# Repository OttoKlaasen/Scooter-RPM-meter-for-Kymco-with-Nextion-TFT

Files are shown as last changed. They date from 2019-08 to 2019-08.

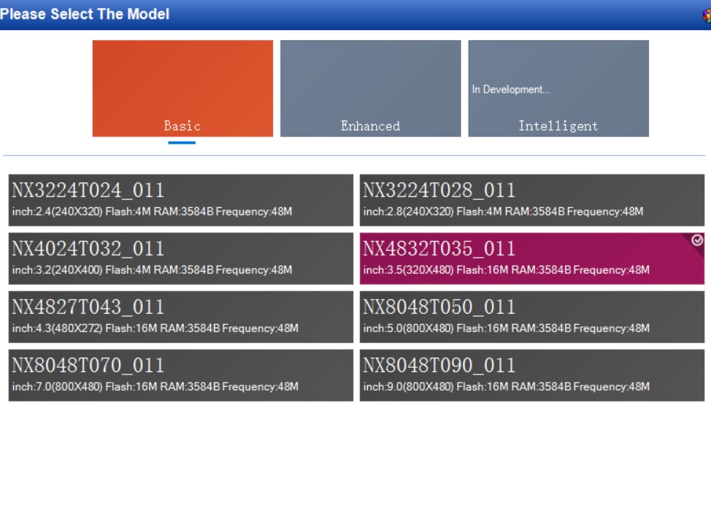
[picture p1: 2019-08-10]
Nextion Display used.jpg

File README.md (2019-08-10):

# Scooter-RPM-meter-for-Kymco-with-Nextion-TFT
Scooter-RPM-meter-for-Kymco-with-Nextion-TFT, display has yellow Ferrari RPM display, RTC on board, Temp and humid meter and oil meter.
Of course this can be used for any brand of scooter, i have a kymco agility 50cc.
This RPM meter goes to 8000 RPM and has been tested for many months and works great.

This project contains the Arduino code, all STL files for printing, the images file for your Nextion Display and a circuit for the pickup detector.
For the pickup detector i have PCB's available which you have to built yourself, you can have one PCB (without components for 2 euro excluding shipping.
The schematic file is on this page.

The Arduino i used is an Arduina Nano, further I used a temp.hum sensor and a rtc clock and of course a Nextion Display.

You also need a buck convertor to convert the 12V bat supply to 5V for the Arduina, the sensor runs on 12V and is interface with an opto-coupler on the main board. Schematic for the main board i dont have, should be easy to figure out from the code.
If you get stuck while building this you can contact me for help.

The TFT file need to be loaded into the Nextion display with an SD card, place the file in the root of the SD card and power the dispay, the file should be loaded automatically.

Temp/Hum meter:  https://nl.aliexpress.com/item/32759158558.html?spm=a2g0s.9042311.0.0.27424c4dwhILO9

RTC: https://nl.aliexpress.com/item/2037934408.html?spm=a2g0s.9042311.0.0.27424c4dwhILO9

Oil Temp meter: https://nl.aliexpress.com/item/1297739612.html?spm=a2g0s.9042311.0.0.27424c4d40bAqC

Nextion Display:  https://nl.aliexpress.com/item/32810467897.html?spm=a2g0s.9042311.0.0.27424c4dopPIMa

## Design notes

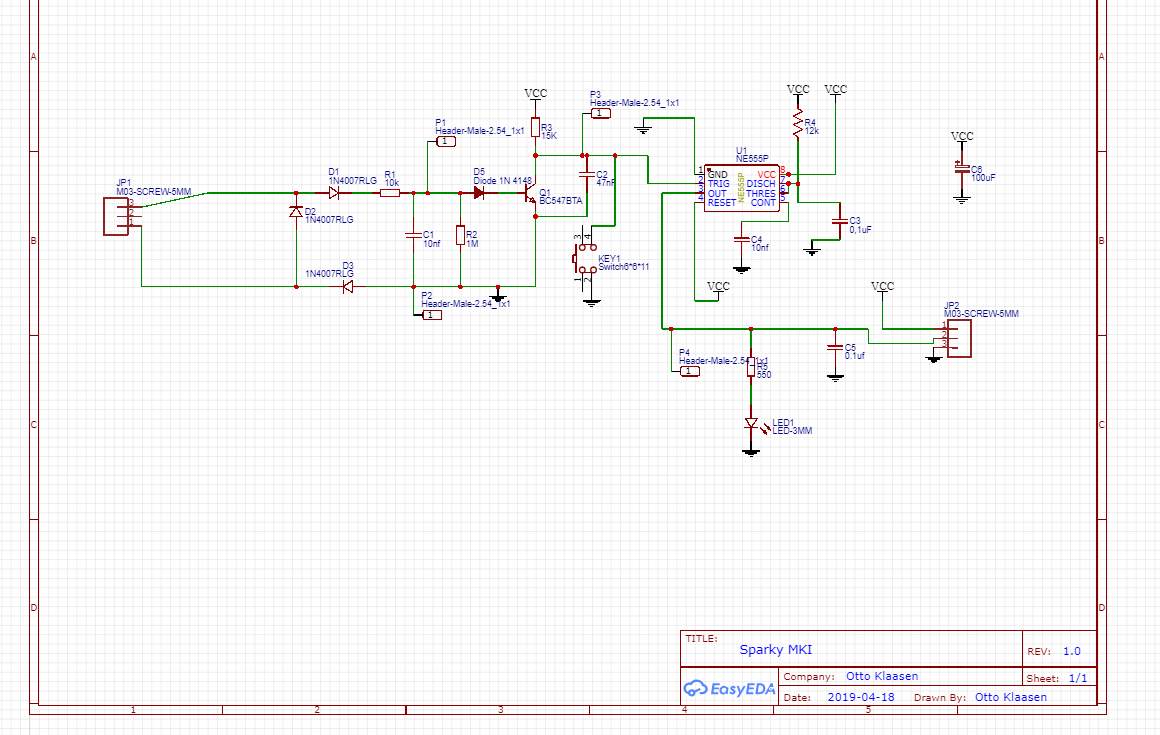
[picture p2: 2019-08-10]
Schematic RPM pickup.png

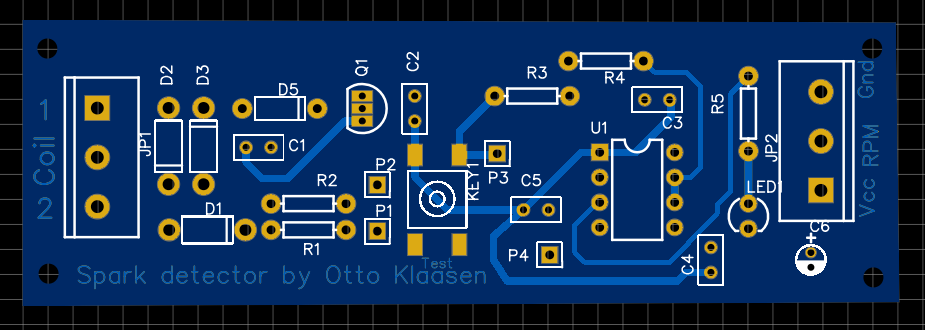
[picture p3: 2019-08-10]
SparkyBoardLayout.png

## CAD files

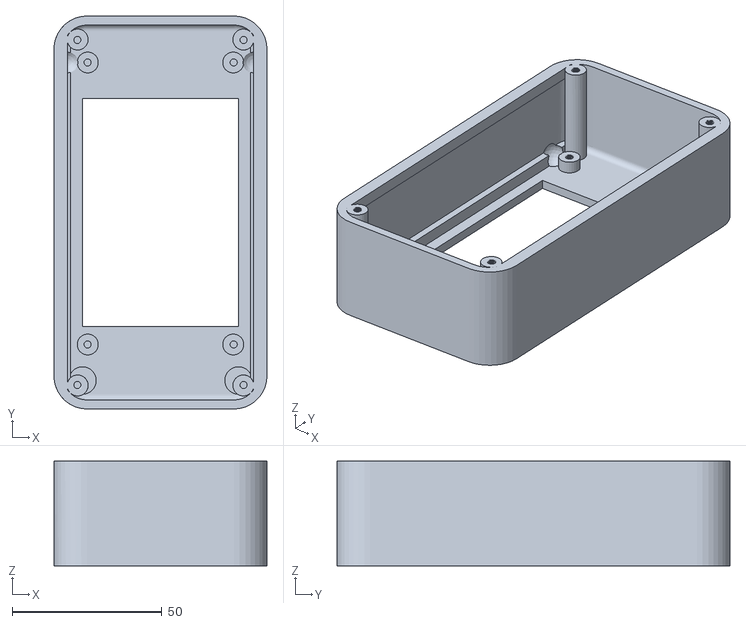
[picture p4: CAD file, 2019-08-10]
KymcoVersionV4AssemblyStressHoles.stl
71.0 x 131.0 x 35.0

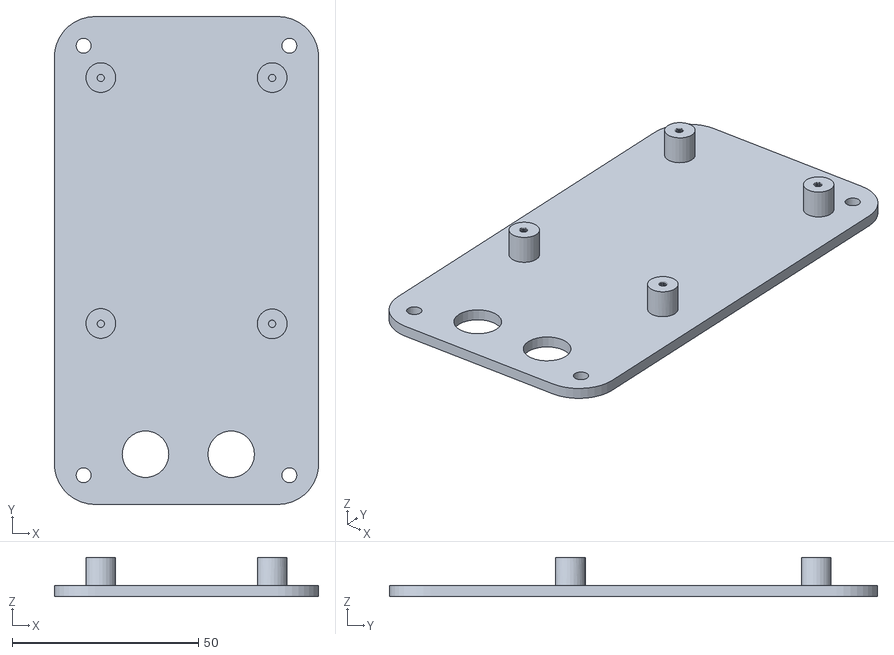
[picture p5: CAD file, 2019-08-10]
CoverKymcoRPM.stl
71.0 x 131.0 x 10.5

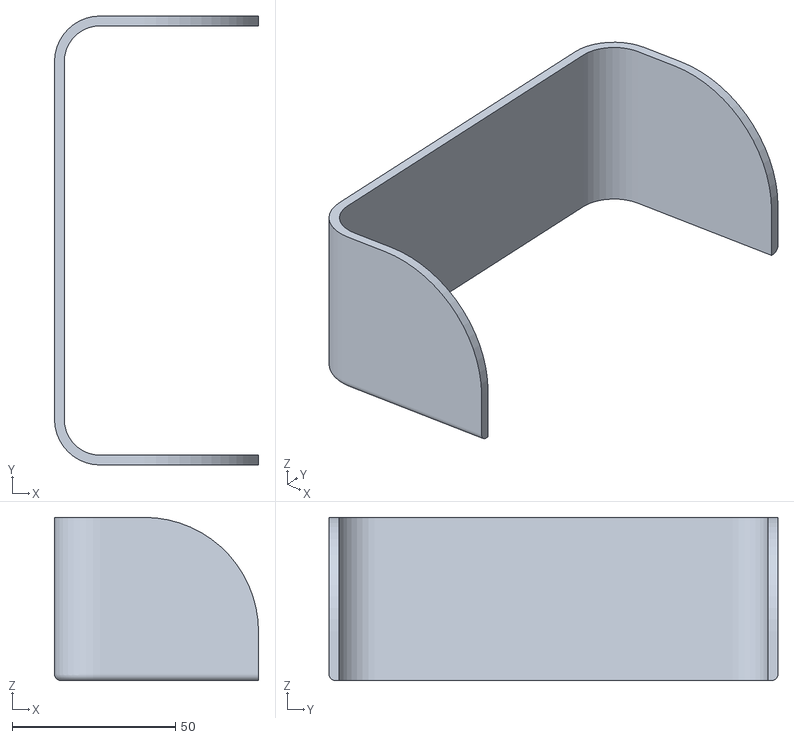
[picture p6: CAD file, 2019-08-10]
SunCoverV3.stl
62.5 x 137.5 x 50.0

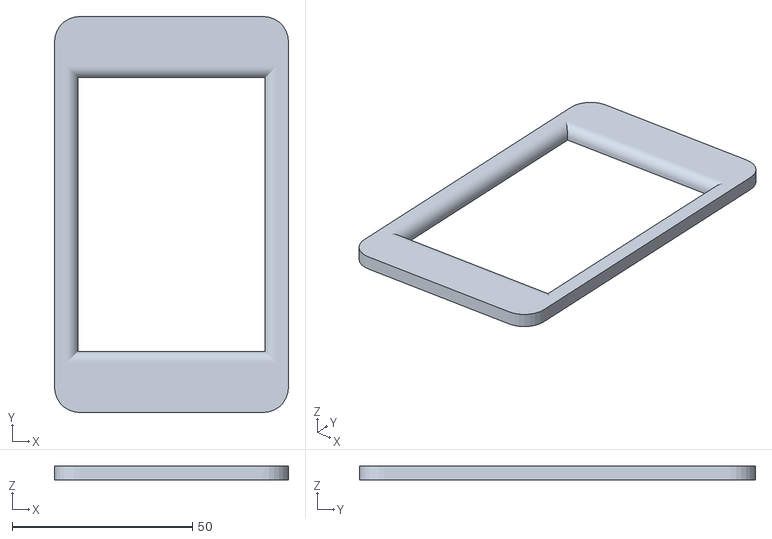
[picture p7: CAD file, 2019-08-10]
Front.stl
65.0 x 110.0 x 4.00

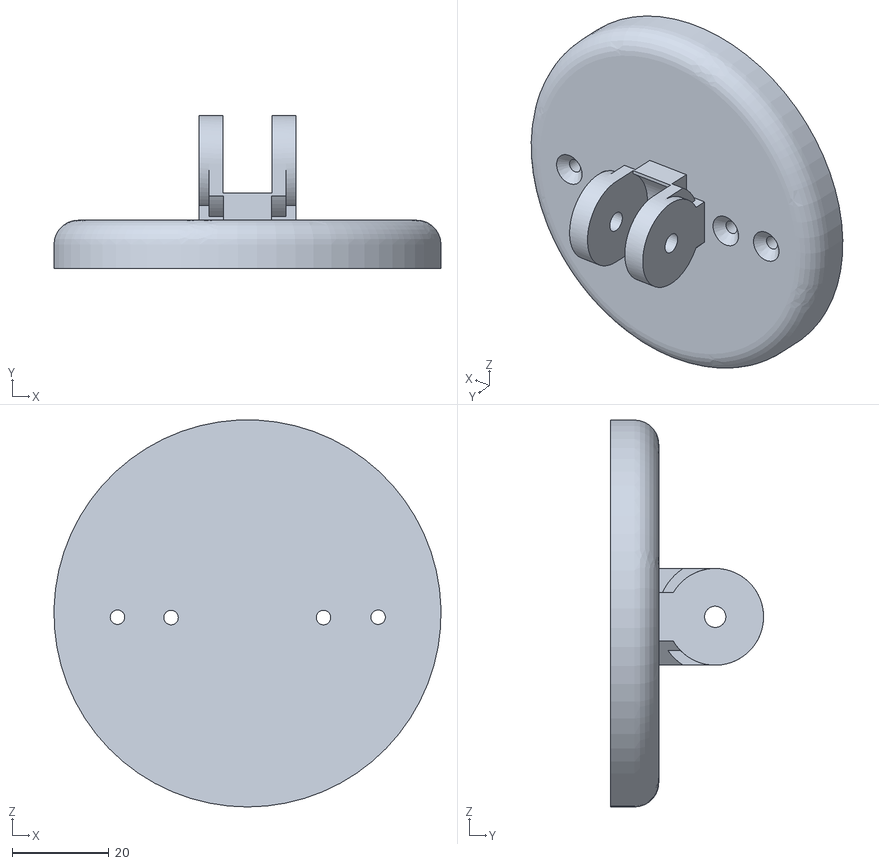
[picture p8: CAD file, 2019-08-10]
HolderForScootComputerVersion2_RotationUnit.stl
80.0 x 31.7 x 80.0

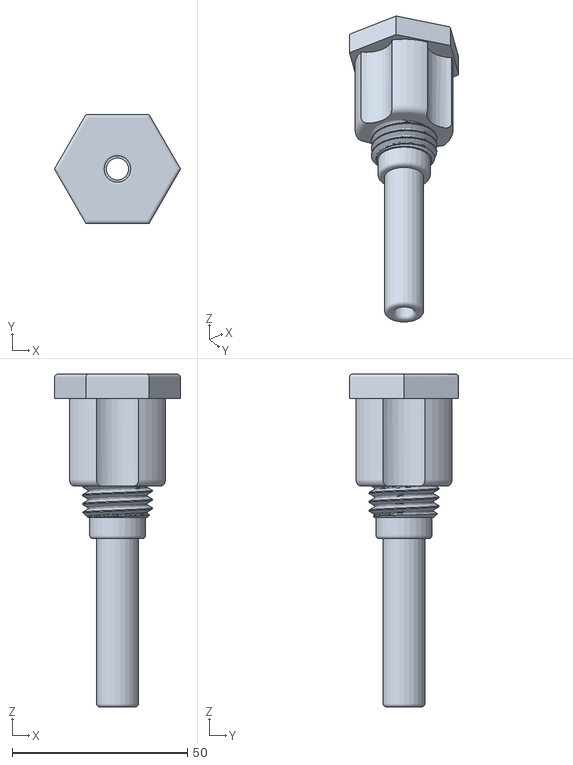
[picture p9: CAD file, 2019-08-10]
OilTempProbeV6_DifferentBarrel.stl
36.0 x 31.2 x 95.0

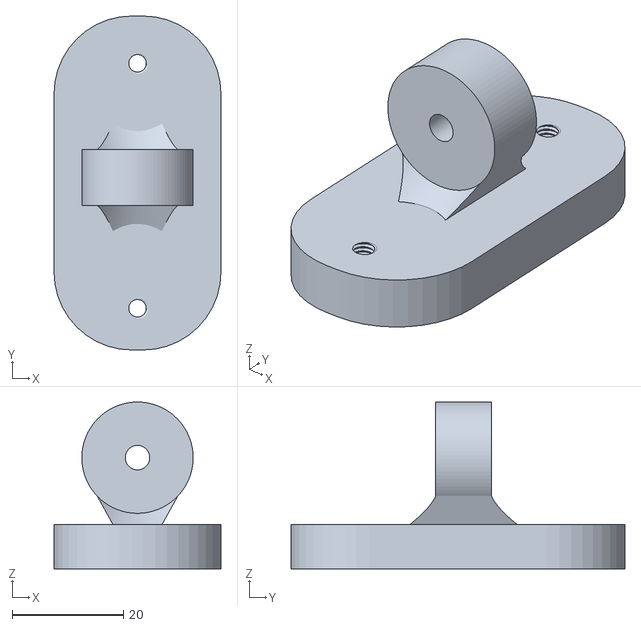
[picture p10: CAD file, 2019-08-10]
RotationHolderWithTwoScrewHoles.stl
30.0 x 60.0 x 30.0

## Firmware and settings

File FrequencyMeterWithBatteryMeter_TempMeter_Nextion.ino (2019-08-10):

// Base Code for pulse detection from https://engmousaalkaabi.blogspot.com/2016/11/ac-220v-frequency-counter-using-arduino.html
// Rewritten by Otto M.Klaasen (c) 2018/2019
// This code also has a battery voltage meter and an oil temperature sensor.
// This version also includes a Nextion Display so we can display the data to a Nextion Display
// In april 2019 we added a temp/hum meter and a rtc clock.

#include <LiquidCrystal.h>
#include <OneWire.h>
#include <stdlib.h>

// Define the number of samples to keep track of. The higher the number, the
// more the readings will be smoothed, but the slower the output will respond to
// the input. Using a constant rather than a normal variable lets us use this
// value to determine the size of the readings array.

const int numReadings = 3;      // Size of the filter

int readings[numReadings];      // the readings from the analog input
int readIndex = 0;              // the index of the current reading
int total = 0;                  // the running total
int average = 0;                // the average

// DHT Temperature & Humidity Sensor
// Unified Sensor Library Example
// Written by Tony DiCola for Adafruit Industries
// Released under an MIT license.

// REQUIRES the following Arduino libraries:
// - DHT Sensor Library: https://github.com/adafruit/DHT-sensor-library
// - Adafruit Unified Sensor Lib: https://github.com/adafruit/Adafruit_Sensor

#include <Adafruit_Sensor.h>
#include <DHT.h>
#include <DHT_U.h>

#define DHTPIN 2      // Digital pin connected to the DHT sensor 
#define BLINKLED  7   // Shows interrupt running

// Feather HUZZAH ESP8266 note: use pins 3, 4, 5, 12, 13 or 14 --
// Pin 15 can work but DHT must be disconnected during program upload.
// Uncomment the type of sensor in use:
//#define DHTTYPE    DHT11     // DHT 11
#define DHTTYPE    DHT22     // DHT 22 (AM2302)
//#define DHTTYPE    DHT21     // DHT 21 (AM2301)

// See guide for details on sensor wiring and usage:
//   https://learn.adafruit.com/dht/overview

DHT_Unified dht(DHTPIN, DHTTYPE);
uint32_t delayMS;

// DS3231_Serial
// To use the hardware I2C (TWI) interface of the Arduino you must connect
// the pins as follows:
//
// Arduino Uno/2009:
// ----------------------
// DS3231:  SDA pin   -> Arduino Analog 4 or the dedicated SDA pin
//          SCL pin   -> Arduino Analog 5 or the dedicated SCL pin
//
// Arduino Leonardo:
// ----------------------
// DS3231:  SDA pin   -> Arduino Digital 2 or the dedicated SDA pin
//          SCL pin   -> Arduino Digital 3 or the dedicated SCL pin
//
// Arduino Mega:
// ----------------------
// DS3231:  SDA pin   -> Arduino Digital 20 (SDA) or the dedicated SDA pin
//          SCL pin   -> Arduino Digital 21 (SCL) or the dedicated SCL pin
//
// Arduino Due:
// ----------------------
// DS3231:  SDA pin   -> Arduino Digital 20 (SDA) or the dedicated SDA1 (Digital 70) pin
//          SCL pin   -> Arduino Digital 21 (SCL) or the dedicated SCL1 (Digital 71) pin
//
// The internal pull-up resistors will be activated when using the 
// hardware I2C interfaces.
//
// You can connect the DS3231 to any available pin but if you use any
// other than what is described above the library will fall back to
// a software-based, TWI-like protocol which will require exclusive access 
// to the pins used, and you will also have to use appropriate, external
// pull-up resistors on the data and clock signals.
//

// Driver for the RTC
#include <DS3231.h>
// Init the DS3231 using the hardware interface
DS3231  rtc(SDA, SCL);


// OneWire DS18S20, DS18B20, DS1822 Temperature Example
//
// http://www.pjrc.com/teensy/td_libs_OneWire.html
//
// The DallasTemperature library can do all this work for you!
// https://github.com/milesburton/Arduino-Temperature-Control-Library

OneWire  ds(10);  // on pin 10 (a 4.7K resistor is necessary)

// setting for Nextion Display
/* 
Connection with Arduino Uno/Nano for the Nextion Display
* +5V = 5V
* TX  = pin 0 (RX)
* RX  = pin 1 (TX)
* GND = GND
*/

int CurrentPage = 0;  // Create a variable to store which page is currently loaded

#include <Nextion.h>  // Include the nextion library (the official one) https://github.com/itead/ITEADLIB_Arduino_Nextion
                      // Make sure you edit the NexConfig.h file on the library folder to set the correct serial port for the display.
                      // By default it's set to Serial1, which most arduino boards don't have.
                      // Change "#define nexSerial Serial1" to "#define nexSerial Serial" if you are using arduino uno, nano, etc.
                      
// Declare objects that we are going to read from the display. This includes buttons, sliders, text boxes, etc:
// Format: <type of object> <object name> = <type of object>(<page id>, <object id>, "<object name>");
/* ***** Types of objects:
 * NexButton - Button
 * NexDSButton - Dual-state Button
 * NexHotspot - Hotspot, that is like an invisible button
 * NexCheckbox - Checkbox
 * NexRadio - "Radio" checkbox, that it's exactly like the checkbox but with a rounded shape
 * NexSlider - Slider
 * NexGauge - Gauge
 * NexProgressBar - Progress Bar
 * NexText - Text box
 * NexScrolltext - Scroll text box
 * NexNumber - Number box
 * NexVariable - Variable inside the nextion display
 * NexPage - Page touch event
 * NexGpio - To use the Expansion Board add-on for Enhanced Nextion displays
 * NexRtc - To use the real time clock for Enhanced Nextion displays
 * *****
 */
 //This was used in orginal nextion demo to switch a LED on Page 1.
NexButton b3 = NexButton(2, 7, "b3");  // Button added for storing RTC data.
// Define number fields at page 2
NexNumber n0 = NexNumber(2,5,"n0");   // Number field on Page 2 for Hours.
NexNumber n1 = NexNumber(2,8,"n1");   // Number field on Page 2 for Minutes.
NexNumber n2 = NexNumber(2,9,"n2");   // Number field on Page 2 for Seconds.
NexNumber n3 = NexNumber(2,16,"n3");  // Number field on Page 2 for Day.
NexNumber n4 = NexNumber(2,17,"n4");  // Number field on Page 2 for Months.
NexNumber n5 = NexNumber(2,18,"n5");  // Number field on Page 2 for Year.
// Day of week
NexText DayOW = NexText(2,19,"t3_2");  // Day of week
// Wave form at page 3
NexWaveform s0  = NexWaveform(3, 1, "s0"); //Declare the WaveForm object
// Next is not used
NexDSButton bt0 = NexDSButton(1, 3, "bt0");  // Dual state button added

// Declare pages:
// Sending data to the display to nonexistent objects on the current page creates an error code sent by the display.
// Any error sent by the display creates lag on the arduino loop because arduino tries to read it, thinking it's a touch event.
// So to avoid this, I am only going to send data depending on the page the display is on.
// That's the reason I want the arduino to know which page is loaded on the display.
// To let arduino know what page is currently loaded, we are creating a touch event for each page.
// On the nextion project, each page must send a simulated "Touch Press Event" in the "Preinitialize Event" section so
// we can register that a new page was loaded.
NexPage page0 = NexPage(0, 0, "page0");  // Page added as a touch event
NexPage page1 = NexPage(1, 0, "page1");  // Page added as a touch event
NexPage page2 = NexPage(2, 0, "page2");  // Page added as a touch event
NexPage page3 = NexPage(3, 0, "page3");  // Page added as a touch event


// Declare touch event objects to the touch event list: 
// You just need to add the names of the objects that send a touch event.
// Format: &<object name>,

NexTouch *nex_listen_list[] = 
{
  &bt0,    // Dual state button added
  &b3,     // Button added
  &n0,     // Number
  &page0,  // Page added as a touch event
  &page1,  // Page added as a touch event
  &page2,  // Page added as a touch event
  &page3,  // Page added as a touch event
    NULL  // String terminated
};  // End of touch event list

int input=13;  // Input for the RPM counter

long high_time;
long low_time;
long time_period;
long freq;
long frequency;
long cRPM;            // Current RPM
long pRPM;            // Previous RPM
int dRPM = 500;       // Delta RPM
long maxRPM = 8000;   // The max RPM we use

float Temperature;

// ************************************************************************************************************************************

void setup()
{
  cRPM = 0;
  pRPM = 0;

  // initialize digital pin LED_BUILTIN as an output.
  pinMode(BLINKLED, OUTPUT);
  
// setup serial communication
  
  Serial.begin(9600);  // Start serial comunication at baud=9600. For Arduino mega you would have to add a
                       // number (example: "Serial1.begin(9600);").
                       // If you use an Arduino mega, you have to also edit everything on this sketch that
                       // says "Serial" and replace it with "Serial1" (or whatever number you are using).

  // Temp and Hum Sensor
  // Initialize device.
  dht.begin();

  // Serial.println(F("DHTxx Unified Sensor Example"));
  // Print temperature sensor details.

  sensor_t sensor;
  dht.temperature().getSensor(&sensor);
//  Serial.println(F("------------------------------------"));
//  Serial.println(F("Temperature Sensor"));
//  Serial.print  (F("Sensor Type: ")); Serial.println(sensor.name);
//  Serial.print  (F("Driver Ver:  ")); Serial.println(sensor.version);
//  Serial.print  (F("Unique ID:   ")); Serial.println(sensor.sensor_id);
//  Serial.print  (F("Max Value:   ")); Serial.print(sensor.max_value); Serial.println(F("°C"));
//  Serial.print  (F("Min Value:   ")); Serial.print(sensor.min_value); Serial.println(F("°C"));
//  Serial.print  (F("Resolution:  ")); Serial.print(sensor.resolution); Serial.println(F("°C"));
//  Serial.println(F("------------------------------------"));
//  Print humidity sensor details.

    dht.humidity().getSensor(&sensor);
//  Serial.println(F("Humidity Sensor"));
//  Serial.print  (F("Sensor Type: ")); Serial.println(sensor.name);
//  Serial.print  (F("Driver Ver:  ")); Serial.println(sensor.version);
//  Serial.print  (F("Unique ID:   ")); Serial.println(sensor.sensor_id);
//  Serial.print  (F("Max Value:   ")); Serial.print(sensor.max_value); Serial.println(F("%"));
//  Serial.print  (F("Min Value:   ")); Serial.print(sensor.min_value); Serial.println(F("%"));
//  Serial.print  (F("Resolution:  ")); Serial.print(sensor.resolution); Serial.println(F("%"));
//  Serial.println(F("------------------------------------"));
// Set delay between sensor readings based on sensor details.

  delayMS = sensor.min_delay / 1000;
  
  // Initialize the rtc object
  rtc.begin();
  
  // The following lines can be uncommented to set the date and time
   //rtc.setDOW(FRIDAY);     // Set Day-of-Week to SUNDAY
   //rtc.setTime(16, 13, 0);     // Set the time to 12:00:00 (24hr format)
   //rtc.setDate(19, 4, 2019);   // Set the date to January 1st, 2014

// Register the event callback functions of each touch event:
// You need to register press events and release events seperatly.
// Format for press events: <object name>.attachPush(<object name>PushCallback);
// Format for release events: <object name>.attachPop(<object name>PopCallback);
b3.attachPush(b3PushCallback);  // Button press
b3.attachPop(b3PopCallback);  // Button release
bt0.attachPush(bt0PushCallback);  // Dual state button bt0 press
page0.attachPush(page0PushCallback);  // Page press event
page1.attachPush(page1PushCallback);  // Page press event
page2.attachPush(page2PushCallback);  // Page press event
page3.attachPush(page3PushCallback);  // Page press event

// End of registering the event callback functions

StartTestGauge(CurrentPage); // Start Gauge test which rotates the gauge at the RPM meter from 0 to 10000 rpm.
  
pinMode(input,INPUT);

 // Average buffer
 // initialize all the readings to 0:
  for (int thisReading = 0; thisReading < numReadings; thisReading++) {
    readings[thisReading] = 0;
  }

  // Setting up interrupts

cli();//stop interrupts

//set timer1 interrupt at 1Hz
  TCCR1A = 0;// set entire TCCR1A register to 0
  TCCR1B = 0;// same for TCCR1B
  TCNT1  = 0;//initialize counter value to 0
  // set compare match register for 1hz increments
  OCR1A = 7812; // = (16*10^6) / (1*1024) - 1 (must be <65536)
  // turn on CTC mode
  TCCR1B |= (1 << WGM12);
  // Set CS10 and CS12 bits for 1024 prescaler
  TCCR1B |= (1 << CS12) | (1 << CS10);  
  // enable timer compare interrupt
  TIMSK1 |= (1 << OCIE1A);

sei();//allow interrupts
}

void loop()
{

// Measure RPM in main loop.
 
low_time=pulseIn(input,LOW);  // Read pulse in ms when input change from high to low.
high_time=pulseIn(input,HIGH);

if (low_time >0 & high_time>0 )  // If both have a value we have measured something !
{
  time_period=high_time+low_time;  // Time period in ms, so if we read 1000 + 12000= 13000
  time_period=time_period/1000;    // Time perion in Arduin to get in ms, so devide 13000/1000= 13ms pulse which is duty cycle.
  frequency=1000/time_period;      // To get frequence devide 1000ms by 13ms which is 76.9 Hz
  cRPM = int(frequency * 60);     // Convert to integer value 
 
  // Dont move RPM to fast, dRPM is the stepping value which is depening on the cRPM
  // You can select two methos of filtering, an average filter of a delta filter.
if (0) { 
    // If 1 use average filter
cRPM = AvgFilter(cRPM);
}
else {
    // Use Delta Filter, this works best with a Kymco Agility Scooter
     if (cRPM > pRPM + dRPM) {
        cRPM = pRPM + dRPM;
        }
     else if (cRPM < pRPM - dRPM) {
        cRPM = pRPM - dRPM;
     }
}

  DisplayRPM(CurrentPage,cRPM); // Send RPM to display.
  DisplayRPMGauge(CurrentPage,cRPM);
  // Update previous value
  pRPM = cRPM;
  
} else {
  cRPM = 0;  // You can increase the value for testing
  DisplayRPM(CurrentPage,cRPM); // Send 0 RPM to display.
  DisplayRPMGauge(CurrentPage,cRPM);
 }
 
// We are going to check the list of touch events we enter previously to
// know if any touch event just happened, and excecute the corresponding instructions:

 nexLoop(nex_listen_list);  // Check for any touch event  

 if(CurrentPage == 0) {
        // Force text fields to correct text when page switching has been done.
        WriteTextFieldPage0();
        // Set the Temp and Humi on Nextion display
        SetTempHumNextion();
      
        // Read the battery voltage.
        int sensorValue = analogRead(A1); //read the A1 pin value
        float R1R2 = (9.82 + 4.62)/4.62;  // we use 9.9K and 4.63K resistor.
        float voltage = sensorValue * (5.00 / 1023.00) * R1R2; //convert the value to a true voltage.
                 
        DisplayBatteryVoltage(CurrentPage,voltage); // Send voltage to display.

        // Read the temperature of the oil
 
        Temperature = ReadtemperatuurSensor();
        if ( Temperature != 0)  DisplayOilTemperature(CurrentPage,Temperature); // Send voltage to display.
 }
    
  if (CurrentPage == 2)
  {
    // Setup for the clock setup
    // Clock will be set when the button is presses in the UI which will trigger subroutine.
   }
  if (CurrentPage == 3)
  {
    // Display Wave of RPM on page 4, the update of the screen depends on the RPM detected.
    if (cRPM > 0 and cRPM < maxRPM){
        DisplayWave(CurrentPage,cRPM);
    }
   }
 }


// ********************************************************************************

// Here we have the functions

// Timer interrupt routine.

ISR(TIMER1_COMPA_vect){  //change the 0 to 1 for timer1 and 2 for timer2
//interrupt commands here
// Run indicator
digitalWrite(BLINKLED, HIGH);   // turn the LED on (LOW is the voltage level)
       
// Set the clock on Nextion display
if (CurrentPage==0) {
  SetClockNextion(CurrentPage);
}
if (CurrentPage==2) {
  SetUpClockNextion(CurrentPage);
}
digitalWrite(BLINKLED, LOW);   // turn the LED OFF (HIGH is the voltage level)
}

// ********************************************************************************
float ReadtemperatuurSensor(){  //This function reads the temperature from the oil.
byte i;
  byte present = 0;
  byte type_s;
  byte data[12];
  byte addr[8];
  float celsius;
  
  if ( !ds.search(addr)) {
    //Serial.println("No more addresses.");
    //Serial.println();
    ds.reset_search();
    delay(5);
    return;
   }
  
  //Serial.print("ROM =");
  //for( i = 0; i < 8; i++) {
    //Serial.print(addr[i], HEX);
  //}

  if (OneWire::crc8(addr, 7) != addr[7]) {
      //Serial.println("CRC is not valid!");
      return;
  }
  //Serial.println();
 
  // the first ROM byte indicates which chip
  switch (addr[0]) {
    case 0x10:
      //Serial.println("  Chip = DS18S20");  // or old DS1820
      type_s = 1;
      break;
    case 0x28:
      //Serial.println("  Chip = DS18B20");
      type_s = 0;
      break;
    case 0x22:
      //Serial.println("  Chip = DS1822");
      type_s = 0;
      break;
    default:
      //Serial.println("Device is not a DS18x20 family device.");
      return;
  } 

  ds.reset();
  ds.select(addr);
  ds.write(0x44, 1);        // start conversion, with parasite power on at the end
  
  delay(5);     // maybe 5ms is enough, maybe not
  // we might do a ds.depower() here, but the reset will take care of it.
  
  present = ds.reset();
  ds.select(addr);    
  ds.write(0xBE);         // Read Scratchpad

  //Serial.print("  Data = ");
  //Serial.print(present, HEX);
  //Serial.print(" ");
  for ( i = 0; i < 9; i++) {           // we need 9 bytes
    data[i] = ds.read();
    //Serial.print(data[i], HEX);
    //Serial.print(" ");
  }
  //Serial.print(" CRC=");
  //Serial.print(OneWire::crc8(data, 8), HEX);
  //Serial.println();

  // Convert the data to actual temperature
  // because the result is a 16 bit signed integer, it should
  // be stored to an "int16_t" type, which is always 16 bits
  // even when compiled on a 32 bit processor.
  int16_t raw = (data[1] << 8) | data[0];
  if (type_s) {
    raw = raw << 3; // 9 bit resolution default
    if (data[7] == 0x10) {
      // "count remain" gives full 12 bit resolution
      raw = (raw & 0xFFF0) + 12 - data[6];
    }
  } else {
    byte cfg = (data[4] & 0x60);
    // at lower res, the low bits are undefined, so let's zero them
    if (cfg == 0x00) raw = raw & ~7;  // 9 bit resolution, 93.75 ms
    else if (cfg == 0x20) raw = raw & ~3; // 10 bit res, 187.5 ms
    else if (cfg == 0x40) raw = raw & ~1; // 11 bit res, 375 ms
    //// default is 12 bit resolution, 750 ms conversion time
  }
  celsius = (float)raw / 16.0;
  //Serial.print("  Temperature = ");
  //Serial.print(celsius);
  //Serial.print(" Celsius, ");

  return celsius;
}
// End of float ReadtemperatuurSensor() fucntion
// ********************************************************************************

////////////////////////// Touch events:
// Each of the following sections are going to run everytime the touch event happens:
// Is going to run the code inside each section only ones for each touch event.

void b3PushCallback(void *ptr)  // Press event for button b3
{
  digitalWrite(13, LOW);  // Turn ON internal LED
  // Get clock settings from page 2
  uint32_t vHour = 0;  // Create variable to store value we are going to get
  n0.getValue(&vHour);  // Read value of number field.
  
  uint32_t vMin = 0;  // Create variable to store value we are going to get
  n1.getValue(&vMin);  // Read value of number field.
  
  uint32_t vSec = 0;  // Create variable to store value we are going to get
  n2.getValue(&vSec); //Read value of number field. 
  
  uint32_t vDay = 0;  // Create variable to store value we are going to get
  n3.getValue(&vDay);  // Read value of number field. 
  
  uint32_t vMonth = 0;  // Create variable to store value we are going to get
  n4.getValue(&vMonth);  // Read value of number field. 
  
  uint32_t vYear = 0;  // Create variable to store value we are going to get
  n5.getValue(&vYear);  // Read value of number field.

   char text_char[12]; 
   memset(text_char, 0, sizeof(text_char)); // Clear buffer
   DayOW.getText(text_char, 12); // Read text field t3 on page 2
   String MyDow = text_char;
   // Set the day of the week       
   if (MyDow == "Monday"){ 
    rtc.setDOW(MONDAY);
   }
   if (MyDow == "Tuesday"){ 
    rtc.setDOW(TUESDAY);
   }
   if (MyDow == "Wednesday"){ 
    rtc.setDOW(WEDNESDAY);
   }
   if (MyDow == "Thursday"){ 
    rtc.setDOW(THURSDAY);
   } 
   if (MyDow == "Friday"){ 
    rtc.setDOW(FRIDAY);
   }
   if (MyDow == "Saturday"){ 
    rtc.setDOW(SATURDAY);
   }
   if (MyDow == "Sunday"){ 
    rtc.setDOW(SUNDAY);
   }
   
   rtc.setTime(vHour, vMin, vSec);     // Set the time to 12:00:00 (24hr format)
   rtc.setDate(vDay, vMonth, vYear);   // Set the date to January 1st, 2014
   digitalWrite(13, HIGH);  // Turn ON internal LED
}  // End of press event

// ********************************************************************************
void b3PopCallback(void *ptr)  // Release event for button b1
{
   // digitalWrite(13, LOW);  // Turn OFF internal LED
}  // End of release event

// ********************************************************************************
void bt0PushCallback(void *ptr)  // Press event for dual state button bt0
{
  uint32_t number5 = 0;  // Create variable to store value we are going to get
  bt0.getValue(&number5);  // Read value of dual state button to know the state (0 or 1)

  if(number5 == 1){  // If dual state button is equal to 1 (meaning is ON)...
    digitalWrite(13, HIGH);  // Turn ON internal LED
  }else{  // Since the dual state button is OFF...
    digitalWrite(13, LOW);  // Turn OFF internal LED
  }
}  // End of press event

// ********************************************************************************

// Page change event:
void page0PushCallback(void *ptr)  // If page 0 is loaded on the display, the following is going to execute:
{
  CurrentPage = 0;  // Set variable as 0 so from now on arduino knows page 0 is loaded on the display
}  // End of press event

// ********************************************************************************
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
